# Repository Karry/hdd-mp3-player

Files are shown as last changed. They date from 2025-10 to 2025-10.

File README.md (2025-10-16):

# HDD MP3 player

Archive repository for DIY MP3 player with ATA hardisk. 
This project is dead and not atively maintained, I publish it 
here on Github just to be available for indexing and to be reachable non-Czech speakers.

[Original webside](https://www.karry.cz/mp3_player/) (in Czech) with various materials, story, photos...

<p align="center">
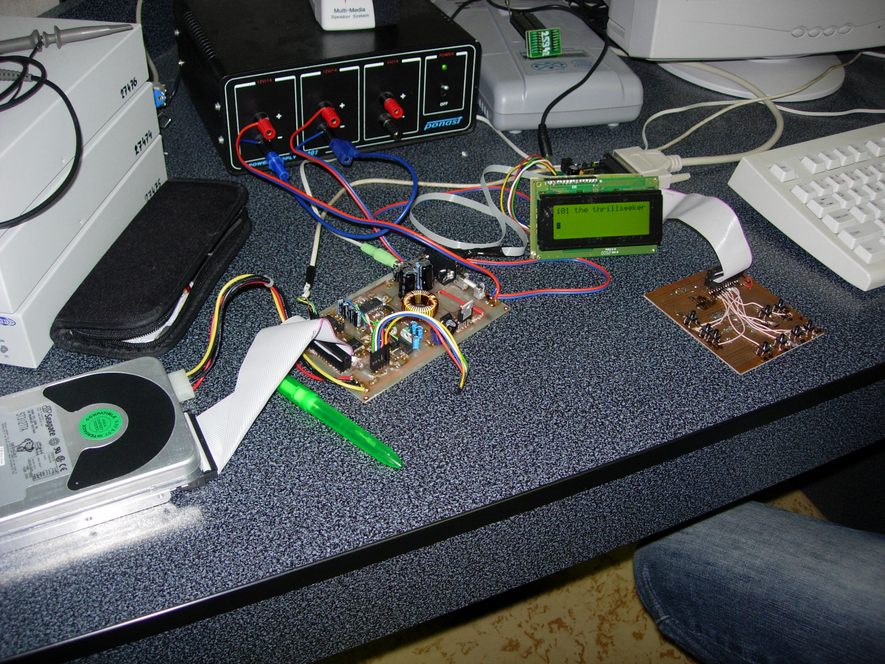
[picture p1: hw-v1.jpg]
first variant
  
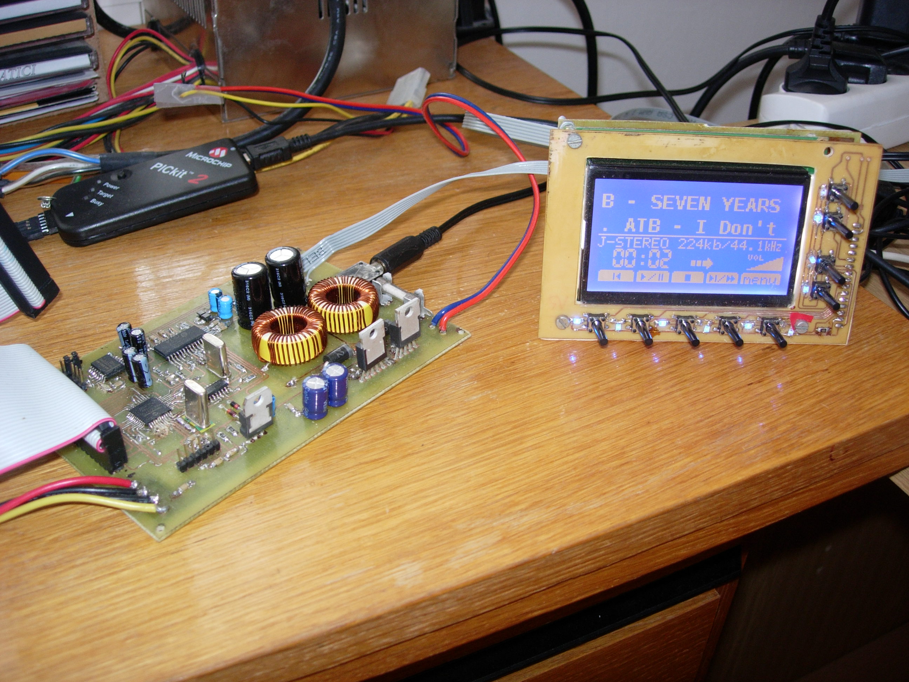
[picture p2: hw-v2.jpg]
second variant
  
</p>

This is software part of my highshcool project for microprocessor course.
It was created in year 2005 when cheap mobile phones was unable to play music, 
portable mp3 players has usual memory 128 MiB and having mp3 player with 20 GiB 
of storage was a dream of many of us.

So, I created harware with two [PIC 16F877A](https://www.microchip.com/en-us/product/pic16f877a)
microprocessors and mp3 decoder on chip [VS1001k](https://www.vlsi.fi/en/products/vs1001.html)
that was able read files from ATA discs with FAT32 filesystem and play them.

 - first PIC microprocessor was connected to HDD via ATA bus
   and via serial SPI bus to the VS1001k ("execution" part)
 - it was able use hard-drives with LBA28 or LBA48 addressing,
   and read FAT32 filesystem - maximum partition size is 2 TiB. 
 - second PIC microprocessor was connected to LCD display and keyboard ("command" part)
 - two PIC microprocessor was communicating via UART (serial protocol)
 - there was two variants of "command" part, first was used small 
   text-based LCD, second variant used 
 - "execution" part and first variant of "command" part was written in assembler,
   second variant of "command" part was written in C partially.

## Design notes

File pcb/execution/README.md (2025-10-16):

Schematic and board was designed in Eagle CAD software.

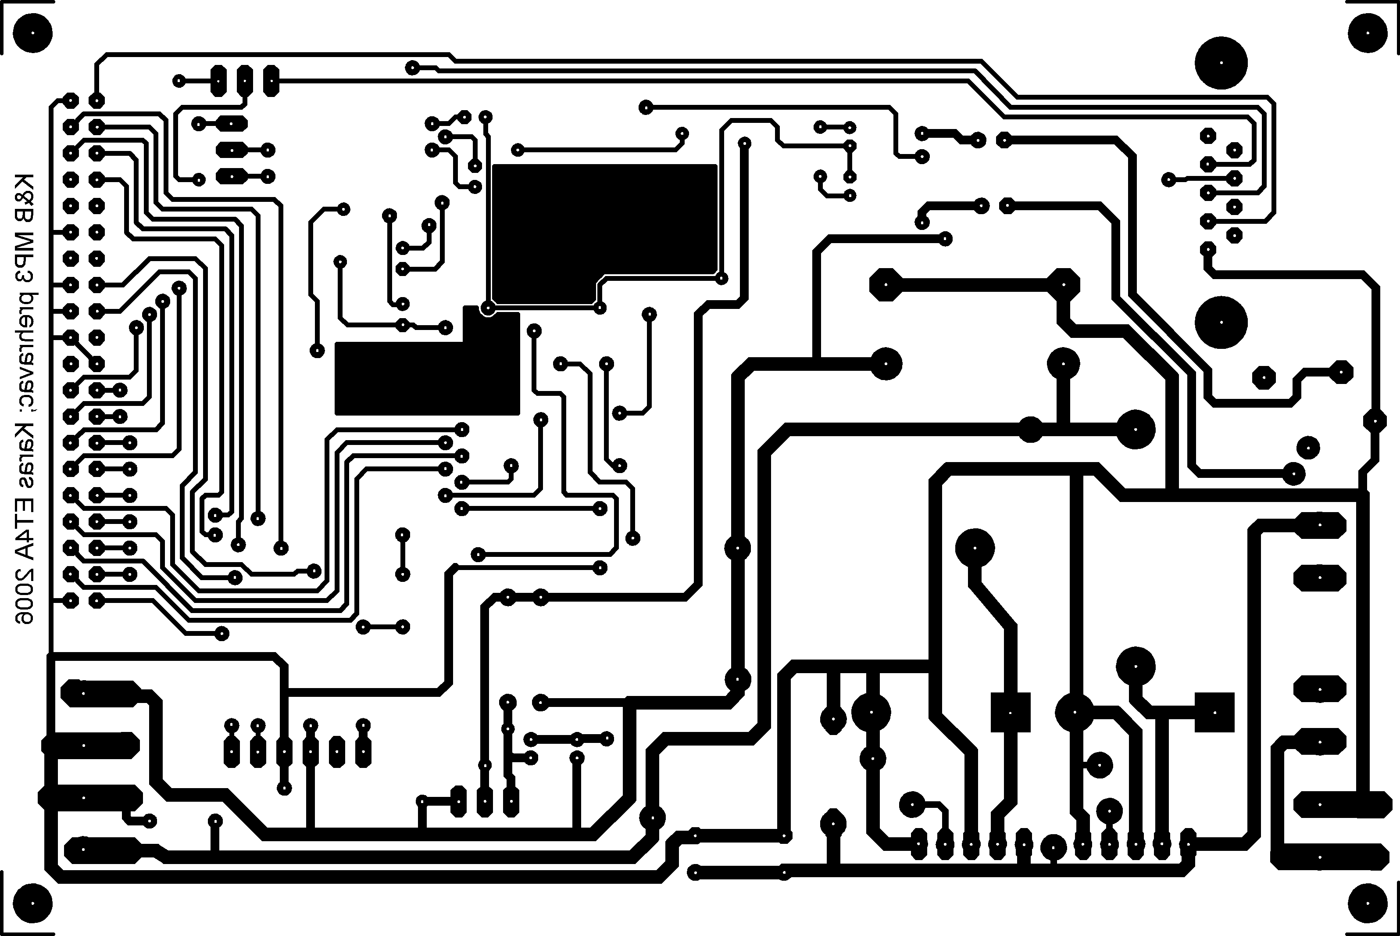
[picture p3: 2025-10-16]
pcb/execution/bottom.PNG

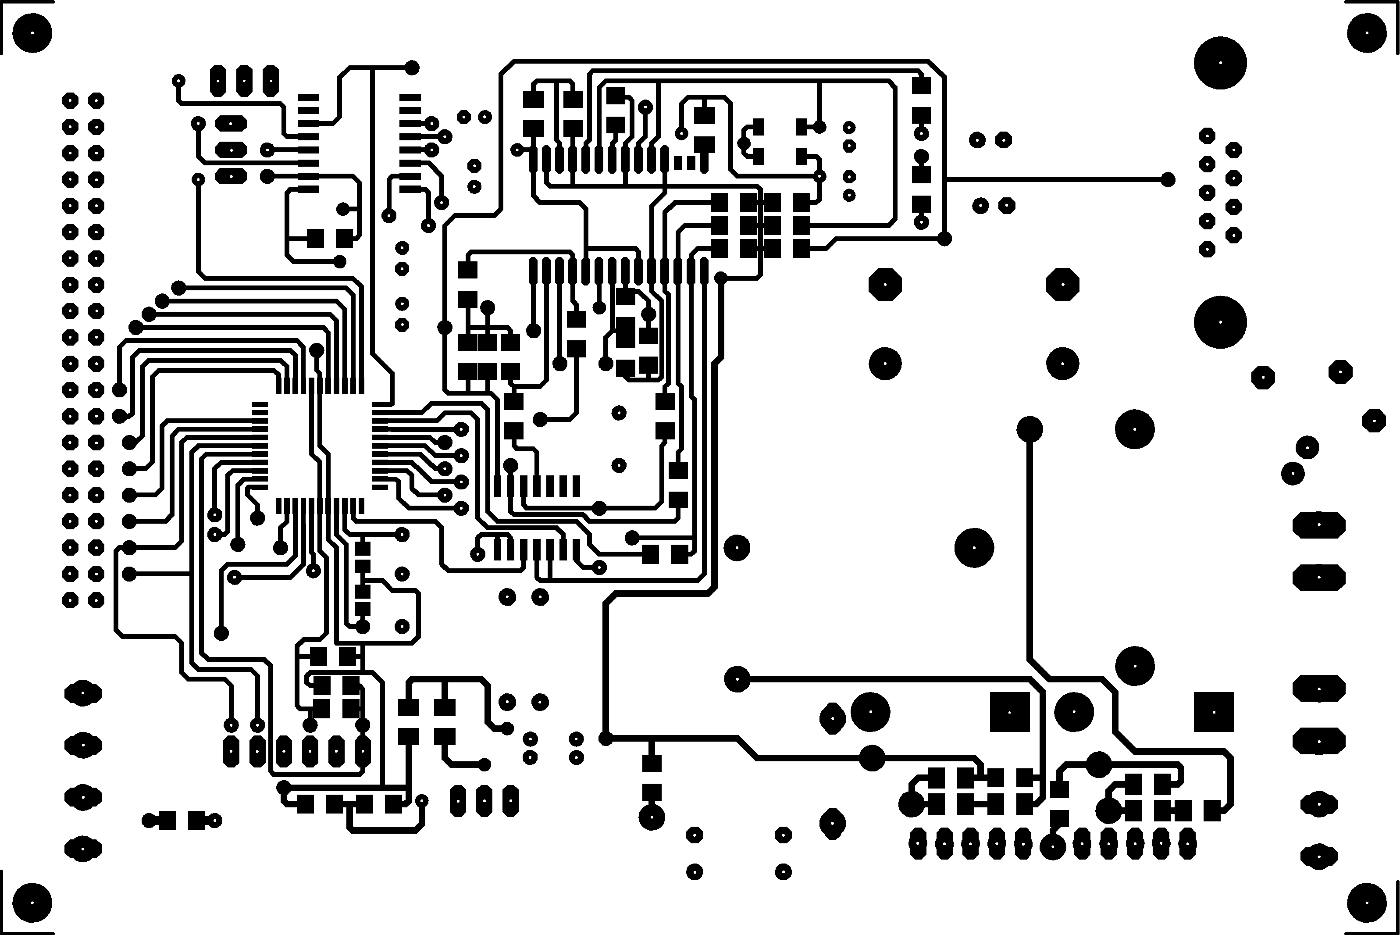
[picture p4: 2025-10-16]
pcb/execution/top.PNG

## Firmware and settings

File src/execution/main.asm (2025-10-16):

;   HLAVNI SOUBOR 
;XXXXXXXXXXXXXXXXXXXXXXXXXXXXXXXXXXXXXXXXXXXXXXXXXXXXXXXXXX
;XXXXXXXXXXXXXXXXXXXXXXXXXXXXXXXXXXXXXXXXXXXXXXXXXXXXXXXXXX
;XXXXXXXXXXXXXXXXXXXXXXXXXXXXXXXXXXXXXXXXXXXXXXXXXXXXXXXXXX
;  MP3 PREPRCAVAC
; ================
; 
; Program mp3 prehravace pouzivajici jako zdroj dat ATA disk.
; 
; Umi identifikovat disk, precist libovolny sektor, v MBR  najit oddily se systemem souboru FAT32, 
; nacist spousteci zaznam FAT32, praci s FAT32, komunikaci s vs1001 a prehravani mp3 pres vs1001.
;
;
; dodelat:
;	- podpora podadresaru pri prehravani
;	- podporu ID3v1
;	- najit a zabit chyby
;
; chyby o kterych vim:
;
; vyreseen chyby:
;	- Pri cteni SCI (registru VS1001k) dochazi k praskani na vystupu a obcas k resetovani dekoderu
;		...vyreseno postavenim konecne faze hardwaru
;	- pri cteni nekterych clusteru jsou precteny clustery jine
;		...tato chyba byla zpusobena chybnym scitanim (MPLAB SIM se chova jinak nez PIC - decf u picu nemeni priznak Carry!!!)
;	- Obcas se nechce vs1001k resetovat. Snad tomu pomuze mala hardwarova uprava.
;		...opravdu tomu znacne pomohlo pridani kondiku a odporu na reset jako u PICu
;
; srpen 2005 - èerven 2006 Karry - lukas.karas@centrum.cz
;XXXXXXXXXXXXXXXXXXXXXXXXXXXXXXXXXXXXXXXXXXXXXXXXXXXXXXXXXX
;XXXXXXXXXXXXXXXXXXXXXXXXXXXXXXXXXXXXXXXXXXXXXXXXXXXXXXXXXX


;**********************************************************
;   VERZE 1.3
;**********************************************************
; !!!!!!!! VSECHNY CASOVE SMYCKY JSOU POCITANY NA Fosc=20MHz !!!!!
; !!!!!!!! NASTAVENI USARTu a SPI TAKY !!!!!!!
	LIST		p=PIC16F877A,C=132,n=60
	__CONFIG	_WDT_OFF & _HS_OSC & _PWRTE_OFF & _BODEN_OFF & _LVP_OFF 
			; LVP_OFF = RB3 jako digitalni I/O
	errorlevel -302		; vypnuti Message [302]: Register in operand not in bank 0.
	errorlevel -306		; vypnuti Message[306] : Crossing page boundary -- ensure page bits are set.
						; ! zjednoduseni vypisu, musim ale davat pozor, z jake banky ctu a kam skacu
;**********************************************************
#DEFINE SPI_SOFTWARE 1		; podmineny preklad. bud je SPI generovana softwarove (0) (jistejsi, pomalejsi]
							; nebo je SPI generovana hardwarove (1)(rychlejsi, neni ale kontrola nad BSYNC)
;**********************************************************

	include "P16F877A.inc" 	; definice blbosti kolem procesoru
	include "mp3.inc" 		; definice promennych, konstant a portu

;XXXXXXXXXXXXXXXXXXXXXXXXXXXXXXXXXXXXXXXXXXXXXXXXXXXXXXXXXX
;XXXXXXXXXXXXXXXXXXXXXXXXXXXXXXXXXXXXXXXXXXXXXXXXXXXXXXXXXX
; PROGRAM
;XXXXXXXXXXXXXXXXXXXXXXXXXXXXXXXXXXXXXXXXXXXXXXXXXXXXXXXXXX
;XXXXXXXXXXXXXXXXXXXXXXXXXXXXXXXXXXXXXXXXXXXXXXXXXXXXXXXXXX
;**********************************************************
 org 0x0000					; PAGE 0
  	goto START
 org 0x0004					; PAGE 0
	movwf TEMP_WORKING
	movfw STATUS
	movwf TEMP_STATUS
	movfw FSR
	movwf TEMP_FSR
	movfw PCLATH
	movwf TEMP_PCLATH
	clrf PCLATH
	BANK_0
	INDF_BANK_0
	goto INTERRUPT
;**********************************************************
 org 0x0010					; PAGE 0
	include "mp3.asm" 		; hlavni programova smycka
	include "ata.asm" 		; podprogramy na ovladani ATA disku
	include "fat32.asm" 	; podprogramy na nacteni a praci s FAT32
	include "aritmetic.asm"	; podprogramy vykonavajici zakladni aritmetologicke operace
 

 org 0x0800					; PAGE 1
	include "vs1001.asm"	; podprogramy na ovladani mp3 decoderu
	include "commands.asm"	; prni cast podprogramu na obsluhu prikazu (od ridiciho procesoru)
	include "filesystem.asm"; podprogramy pro praci s adresari a setrideni obsahu adresaru


 org 0x1000					; PAGE 2
	include "particions.asm"; podprogramy pro analyzu MBR, nacteni a kontrolu FAT oddilu
	include "commands2.asm"	; druha cast podprogramu na obsluhu prikazu (od ridiciho procesoru)
	include "subdirectory.asm"; podpora podadresaru pri prehravani

 org 0x1800					; PAGE 3
	include "loudness.asm"	; plugin dekoderu "loudness" a podprogramy pro jeho nahrani a obsluhu
;**********************************************************
 org	0x2100		; tabulka v pameti EEPROM (256 bytu)
	de	0x30, 0x30, 0xC3, 0x00, 0x00, 0x00, 0x00, 0x00
	de	0x00, 0x00, 0x00, 0x00, 0x00, 0x00, 0x00, 0x00
	de	0x00, 0x00, 0x00
	END
;**********************************************************
; data v EEPROM maji nasledujici vyznam:
;
;  +----------+------------------------+-----------------+ 
;  |  adresa  |  ekvivalentni registr  |  kdy se nacita  |  
;  +----------+------------------------+-----------------+  
;  |   0      | HLASITOST_L            |                 |
;  |   1      | HLASITOST_L            |  pri startu     |
;  |   2      | PREH_STAV0             |                 |
;  |   3      | PREH_STAV1             |                 |
;  +----------+------------------------+-----------------+ 
;  |   4      | ZACATEK_DAT1           |                 |
;  |   5      | ZACATEK_DAT2           |  po naètení oddílu 
;  |   6      | ZACATEK_DAT3           |  se zkontroluje PREH_ADR_CL
;  |   7      | ZACATEK_DAT4           |  v EEPROM, zda se jedna 
;  |   8      | PREH_ADR_CL1           |  o stejny oddil, ktery byl nacten
;  |   9      | PREH_ADR_CL2           |  pri posledni prehrane skladbe,
;  |   A      | PREH_ADR_CL3           |  a pokud ano a zoroven je zvolen
;  |   B      | PREH_ADR_CL4           |  sedmi bit PREH_STAV0 (prehravat
;  |   C      | PREH_ZAZNAM1           |  ihned po nacteni oddilu),
;  |   D      | PREH_ZAZNAM2           |  tak se nactou ostatni hodnoty 
;  |   E      | PREH_CITAC_PREV	       |  z EEPROM. To má za následek, 
;  |   F      | PREH_DATA_CL1          |  ze se zacne prehravat od mista, 
;  |  10      | PREH_DATA_CL2          |  kde se posledne skoncilo...
;  |  11      | PREH_DATA_CL3          |                 |
;  |  12      | PREH_DATA_CL4          |                 |
;  +----------+------------------------+-----------------+ 
;
; vsechny hodnoty se do EEPROM z RAM kopiruje pokazde, kdyz skonci MP3

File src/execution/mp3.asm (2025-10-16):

START
	call INIT_CONFIG	; nakonfiguruje preruseni, WDT, USART, pull ups...
	call INIT_PORT		; nastavy trisy, a porty do vychozi polohy

	call DELAY_25us 	; chvili pockame, protoze napjeti zdroje co mam doma (stary PC-AT zdroj)
	call DELAY_25us 	; zezacatku dost kolisa a nepomuze tomu ani POR...
	call DELAY_25us

;LOOP
;	movlw 'O'
;	call WR_USART
;	movlw 'K'
;	call WR_USART
;	call DELAY_200ms
;	call DELAY_200ms
;	goto LOOP


	PROG_PAGE_1
	call VS_INIT
	PROG_PAGE_3
	call VS_LOAD_PLUGIN
	PROG_PAGE_0

	call ATA_RESET				; resetujeme disk, koukneme zda tu nejakej mame
	btfss ATA_ATTRIBUTES,ATA_OK
	goto $-2					; pokud neni pripojen disk, tak se jej pokousime neustale najit...
	nop							; ...pokud tam zadny disk neni, tak bychom se stejne ani sem nemeli dostat, protoze budem porad cekat na WAIT_FOR_READY

	call IDENTIFY_DEVICE		; koukneme co disk umi

CEK_PRIKAZ_01h
	PROG_PAGE_1
	call CEKEJ_PRIKAZ
	PROG_PAGE_0

	movfw 0x078					; prvni byte prikazoveho zasobniku
	clrf PRIJATYCH_DAT			; prikaz byl vybran -> prazdny zasobnik
	sublw h'01'					; ...pokud to byl prikaz 01h...
	btfss STATUS,Z
	goto CEK_PRIKAZ_01h

	movfw ATA_ATTRIBUTES		; ...vodesleme zpet vlastnosti disku a jeho jmenovku (vis. popis protokolu)
	call WR_USART
	call ODESLI_MODEL_NUMBER	; odesleme jmeno disku 


	PROG_PAGE_2
	call SCAN_MBR				; najdeme oddily s FAT32 a jejich seznam dame do bufferu 2
	PROG_PAGE_0
CEK_PRIKAZ_02h_03h
	PROG_PAGE_1
	call CEKEJ_PRIKAZ			; pockame si na prikaz
	clrf STAV_PRIKAZU			; smazeme registr signalizujici platnost prikazu
	call PRIKAZ_02h				; testujeme zda prisel prikaz 02h, pokud ano tak jej provedeme a nastavime platnost prikazu
	PROG_PAGE_2
	call PRIKAZ_03h				; ---//---
	PROG_PAGE_0
	btfss STAV_PRIKAZU,0		; Pokud si zadna z procedur prikaz neprevzala, ...
	clrf PRIJATYCH_DAT			; ...vymazeme zasobnik prikazu. (prikaz neni pro tuto chvili platny)
	btfss ATA_ATTRIBUTES,FAT32_LOAD	; cekame dokud nedojde k nasteni nejakeho oddilu
	goto CEK_PRIKAZ_02h_03h		; pokud byl oddil vporadku nacten, pokracujeme...

;********************************************************************************************************************
;********************************************************************************************************************
;********************************************************************************************************************
;********************************************************************************************************************
BIG_LOOP	
	; Tady ta smycka beha po nacteni disku a nejake FATky porad dokola.
	; Pri kazdem prubehu smyckou vyresime prikazy, ktere prisly, a pokud prehravame 
	; nejakou mp3 tak dekoder nakrmime jednim sektorem...
	; Mimo to je v teto smycce osefovano, ze kdyz skonci mp3, nacteme dalsi... (v zavislosti na nastaveni repeatu)
	; pokud se dostaneme na konec slozky a je nastaveno vyhledavani dalsich slozek, tak nejakou najdeme...

	movfw PRIJATYCH_DAT
	andlw h'FF'
	btfsc STATUS,Z
	goto BIG_LOOP__NENI_PRIKAZ
	
	clrf STAV_PRIKAZU			; smazeme registr signalizujici platnost prikazu
	; Pokud jsme tady, tak prisel nejaky prikaz, jdem predat prikaz jednotlivym proceduram
	PROG_PAGE_1
	call PRIKAZ_02h				; testujeme zda prisel prikaz 02h, pokud ano tak jej provedeme a nastavime platnost prikazu
	PROG_PAGE_2
	call PRIKAZ_03h				; --- // ---
	PROG_PAGE_1
	call PRIKAZ_04h				; --- // ---
	call PRIKAZ_05h				; --- // ---
	call PRIKAZ_06h				; --- // ---
	call PRIKAZ_07h				; --- // ---
	call PRIKAZ_08h				; --- // ---
	call PRIKAZ_09h				; --- // ---
	call PRIKAZ_0Ah				; --- // ---
	PROG_PAGE_2
	call PRIKAZ_0Bh				; --- // ---
	call PRIKAZ_0Ch				; --- // ---
	call PRIKAZ_0Dh				; --- // ---
	PROG_PAGE_1

	call PRIKAZ_80h				; --- // ---
	call PRIKAZ_81h				; --- // ---
	call PRIKAZ_82h				; --- // ---
	call PRIKAZ_83h				; --- // ---
	call PRIKAZ_84h				; --- // ---
	PROG_PAGE_2
	call PRIKAZ_85h				; --- // ---
	call PRIKAZ_86h				; --- // ---
	call PRIKAZ_87h				; --- // ---
	PROG_PAGE_0
	
	btfss STAV_PRIKAZU,0		; Pokud si zadna z procedur prikaz neprevzala, ...
	clrf PRIJATYCH_DAT			; ...vymazeme zasobnik prikazu. (prikaz neni pro tuto chvili platny)

BIG_LOOP__NENI_PRIKAZ
	movfw KONST_NECINNOSTI1
	andwf KONST_NECINNOSTI2,w
	sublw h'FF'
	btfsc STATUS,Z
	goto BIG_LOOP__NO_STANDBY	; pokud je KONST_NECINNOSTI = h'FFFF', tak disk nechame porad zapnuty
	
	movfw CITAC_NECINNOSTI1
	iorwf CITAC_NECINNOSTI2,w
	btfsc STATUS,Z
	call ATA_STANDBY			; pokud z disku jsme jiz dlouho nic necetli, tak jej dame do STANDBY
								; potrebna doba je v KONST_NECINNOSTI

BIG_LOOP__NO_STANDBY

	btfss PREH_STAV0,0			; Pokud je zvoleno play,...
	goto MP3_NOT_PLAY

	btfss PREH_STAV0,1			; ...a je co prehravat...
	goto MP3_NOT_PLAY
	
	movfw PREH_DATA_POZICE
	subwf CLUSTER_SIZE,W
	btfss STATUS,Z				; ...podivame se zda jiz nejsme na konci clusteru...
	goto SEND_MP3_DATA

	movfw PREH_D_FRAGMENT1		; ...pokud ano, podivame se zda nejsme na posledni casti fragmentu...
	iorwf PREH_D_FRAGMENT2,w
	btfss STATUS,Z
	goto BIG_LOOP_DEC_FRAGMENT	; ...pokud ne, tak PREH_D_FRAGMENT1-- ; PREH_DATA_CL++

	movfw PREH_DATA_CL1			; ...pokud jo, tak si najdeme dalsi cluster v retezci.
	movwf CLUSTER1
	movfw PREH_DATA_CL2
	movwf CLUSTER2
	movfw PREH_DATA_CL3
	movwf CLUSTER3
	movfw PREH_DATA_CL4
	movwf CLUSTER4

	clrf PREH_DATA_POZICE
	call NEXT_CLUSTER
	
	btfss POZICE,0				; Pokud byl cluster posledni v retezci...
	goto BIG_LOOP_DALSI_FRAGMENT

	call DALSI_SKLADBA			; ...tak najdeme dalsi soubor co se ma prehrat (pokud je nastaven repeat a dalsi kraviny)
	; otestujeme zda se ma nejaka dalsi mp3 prehravat
	btfss PREH_STAV0,0			; Je zvoleno play?
	goto MP3_NOT_PLAY
	btfss PREH_STAV0,1			; Je co prehravat?
	goto MP3_NOT_PLAY
	goto SEND_MP3_DATA

BIG_LOOP_DALSI_FRAGMENT
	movfw CLUSTER1
	movwf PREH_DATA_CL1
	movfw CLUSTER2
	movwf PREH_DATA_CL2
	movfw CLUSTER3
	movwf PREH_DATA_CL3
	movfw CLUSTER4
	movwf PREH_DATA_CL4

	call ZJISTI_FRAGMENT

	movfw FRAGMENT1
	movwf PREH_D_FRAGMENT1
	movfw FRAGMENT2
	movwf PREH_D_FRAGMENT2

	;movlw 'F'
	;call WR_USART

	goto SEND_MP3_DATA
BIG_LOOP_DEC_FRAGMENT
	;----------------------------
	movfw VS_LOUDNESS
	andlw h'FF'
	btfsc STATUS,Z				; pokud je nastaven nejaky filter, tak jej reaktivujeme...
	goto BIG_LOOP_DEC_FRAGMENT_NO_PLUG

	movlw VSADDR_AIADDR
	movwf TEMP1
	movlw 0x00
	movwf TEMP2	
	movlw 0x42
	movwf TEMP3
	PROG_PAGE_1
	call VS_WR_REG				; nastavime zacatek uzivatelskeho programu (0x4200)
	PROG_PAGE_0

	movlw VSADDR_AICTRL0
	movwf TEMP1
	movfw VS_LOUDNESS
	movwf TEMP2	
	movlw 0x00
	movwf TEMP3
	PROG_PAGE_1	
	call VS_WR_REG				; nastavime pozadovany filter
	PROG_PAGE_0
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

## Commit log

2025-10-16 schematics and pcb
    [LCD.brd, LCD.sch, mp3player.brd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]
2025-10-16 execution v0.1 - identify device
2025-10-16 command v0.2 - buttons
